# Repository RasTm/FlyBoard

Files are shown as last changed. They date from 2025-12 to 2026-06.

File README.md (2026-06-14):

Bu proje uçuş kontrol kartımız için gerekli yazılımım içermektedir. Proje tamamlandıkça bu bölüm kullanım klavuzu olarak değiştirilecektir.

Projeyi Atollic ile derleyebilmek için aşağıdaki işlemler yapılmalıdır.

1- Proje açılırken executable değil makefile olarak açılmalıdır.

2- C++ sürümü Properties (Alt+Enter) / C,C++ Build / Settings / Tool Settings / C++ Compiler / General başlığı altından C++ 11 olarak ayarlanmalıdır.

3- Properties (Alt+Enter) / C,C++ General / Paths and Symbols başlığına gidilip Includes, Library Paths, Source Location sekmelerine Libs klasörü eklenmelidir.

4- Properties (Alt+Enter) / C,C++ General / Paths and Symbols başlığına gidilip Includes ve Symbols sekmelerinden STD_Lib ile alakalı her şey kaldırılmalıdır. 

5- Libraries klasöründeki STD_periph klasörü kaldırılmalıdır. 

6- Libraries/Cmsis klasörü içerisine DSP_Lib ve Include klasörleri atılmalıdır eğer uyarı verirse orijinal dosyaların üzerine yazılmalıdır.

7- stm32f4xx_conf.h dosyasında eklenmiş tüm Stdlib kütüphaneleri kaldırılmalıdır.

8- Float değerleri LCD ekran üzerine yazdırmak için snprint fonksiyonu modifiye edilmelidir. Bunun için Properties (Alt+Enter) / C,C++ Build / Settings / Tool Settings / C++ Linker başlığı içerisinde Command alt başlığına "-u_printf_float" ifadesi yazılmalıdır.

9- Debug ekranında başlatmadan önce main'de durmasını sağlayan breakpoint kaldırılmalı yoksa C++ ile geliştirme yaparken program kırılabilir. Kaldırmak için Configure Debug / Startup Scripts gidilmeli. Buranın en altından 
"# Set a breakpoint at main(). tbreak main" Silinmeli.

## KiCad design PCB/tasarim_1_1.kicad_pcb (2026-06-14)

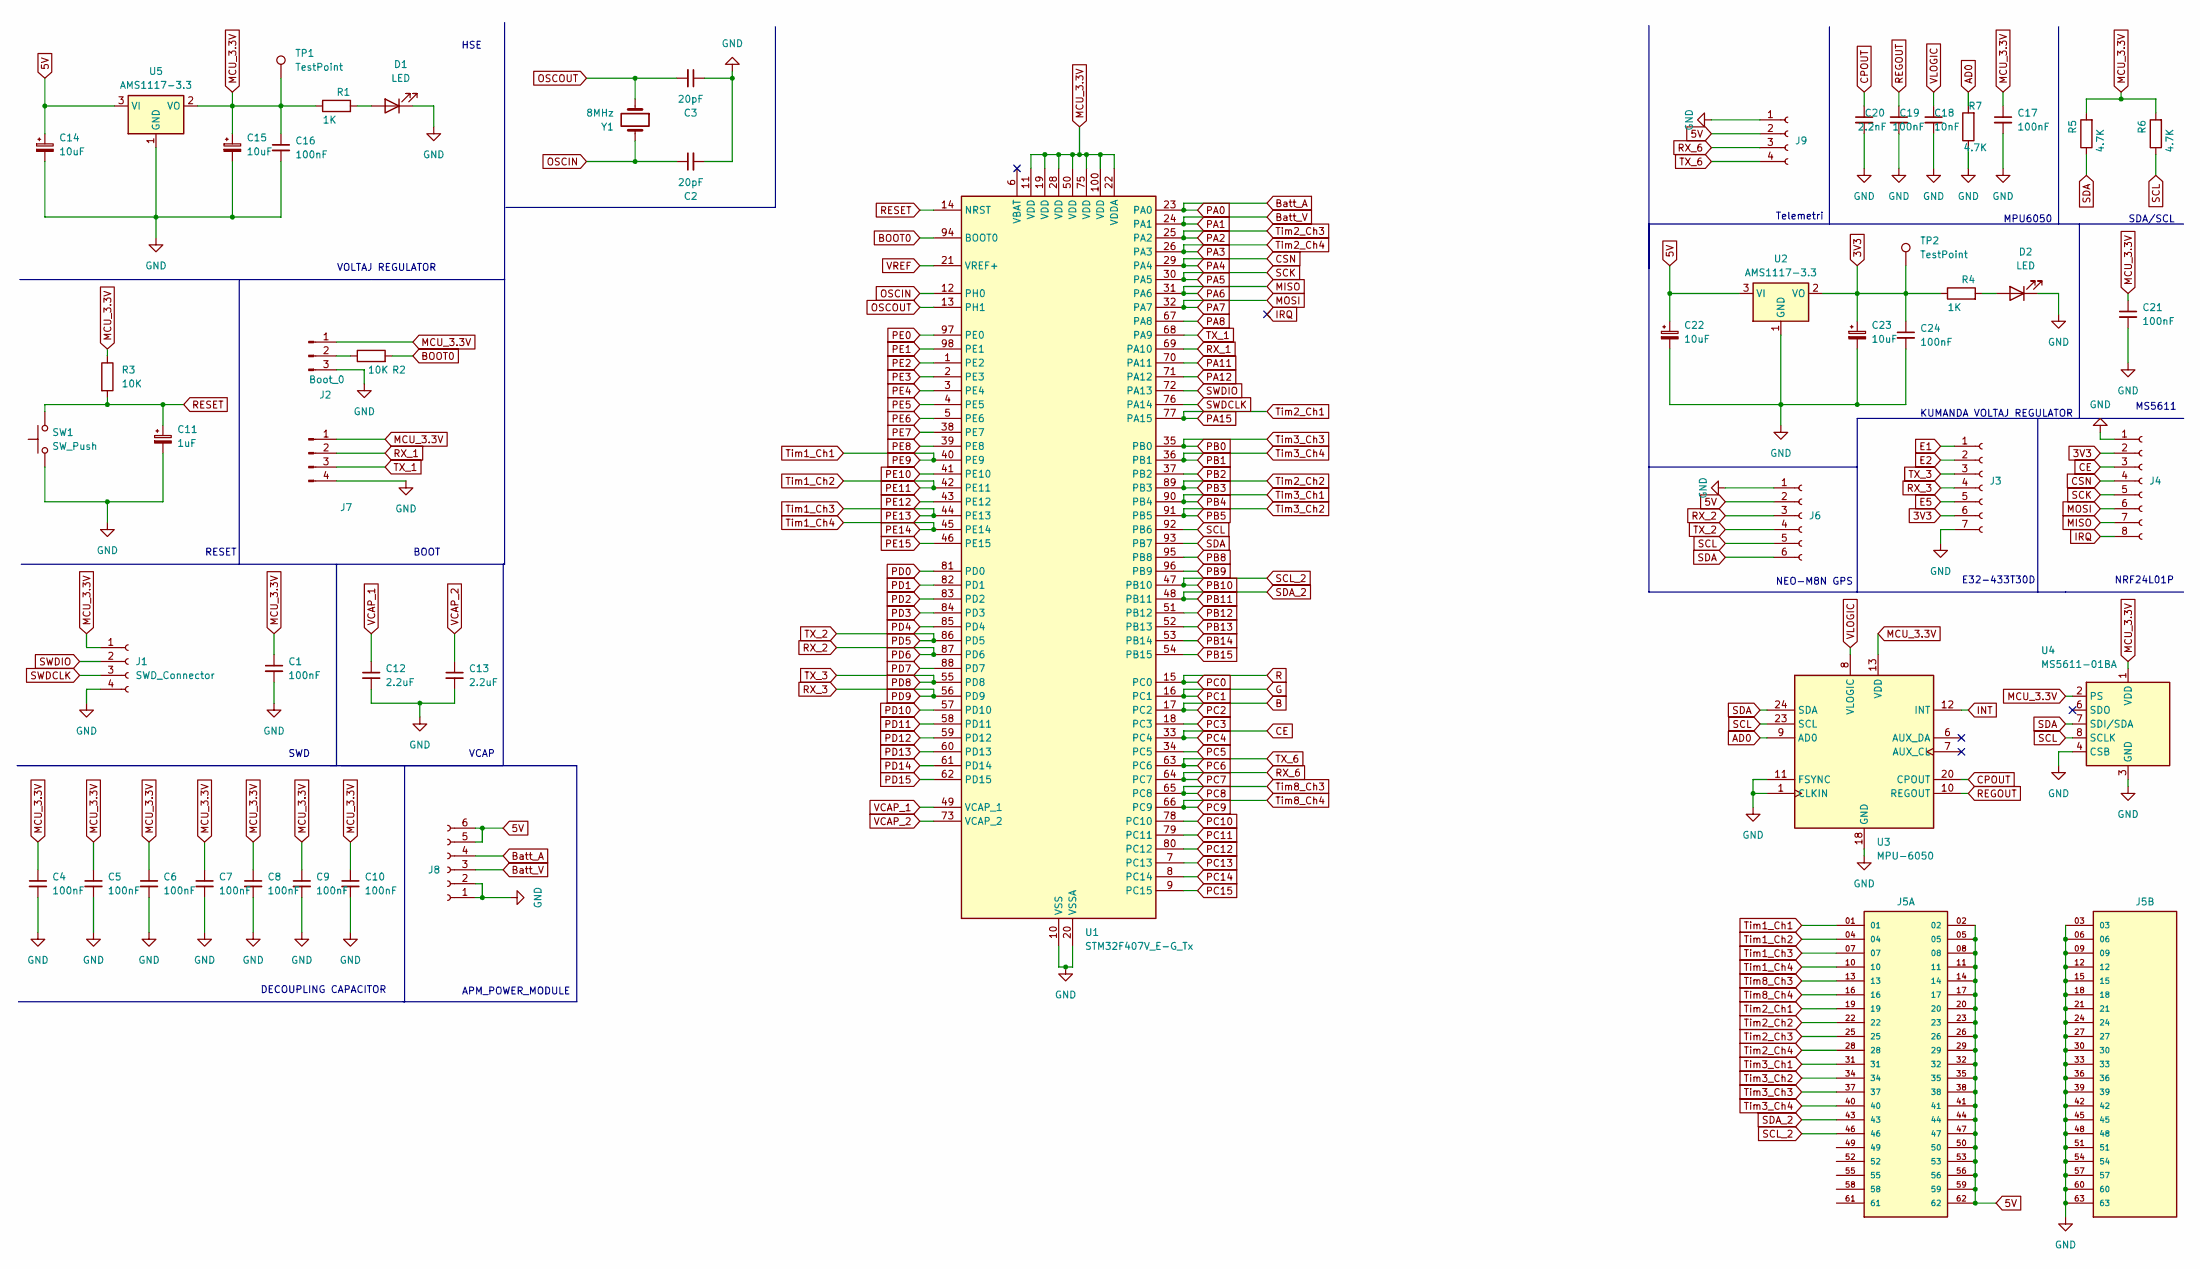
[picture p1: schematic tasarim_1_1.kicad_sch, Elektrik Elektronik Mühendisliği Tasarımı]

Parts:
C1, C4, C5, C6, C7, C8, C9, C10, C16, C17, C19, C21, C24: 100nF; C_0603_1608Metric
C2, C3: 20pF; C_0603_1608Metric
C11: 1uF; CP_EIA-1608-08_AVX-J
C12, C13: 2.2uF; CP_EIA-1608-08_AVX-J
C14, C15, C22, C23: 10uF; CP_EIA-1608-08_AVX-J
C18: 10nF; C_0603_1608Metric
C20: 2.2nF; C_0603_1608Metric
D1, D2: LED; LED_0805_2012Metric
J1: SWD_Connector; PinHeader_1x04_P2.54mm_Horizontal
J2: Boot_0; PinHeader_1x03_P2.54mm_Vertical
J3: LORA_Connector; JST_PH_B7B-PH-K_1x07_P2.00mm_Vertical
J4: NRF_Connector; JST_PH_B8B-PH-K_1x08_P2.00mm_Vertical
J5: ZW-21-08-L-T-200-157; SAMTEC_ZW-21-08-L-T-200-157; PARTREV R
J6: GPS_Connector; Hirose_DF13-06P-1.25DSA_1x06_P1.25mm_Vertical
J7: Bootloader_Port; PinHeader_1x04_P2.54mm_Vertical
J8: APM_Connector; Hirose_DF13-06P-1.25DSA_1x06_P1.25mm_Vertical
J9: Telemetri; JST_PH_B4B-PH-K_1x04_P2.00mm_Vertical
R1, R4: 1K; R_0603_1608Metric
R2, R3: 10K; R_0603_1608Metric
R5, R6, R7: 4.7K; R_0603_1608Metric
SW1: SW_Push; SW_PUSH_6mm_H5mm
TP1, TP2: TestPoint; TestPoint_Pad_D1.0mm
U1: STM32F407V_E-G_Tx; LQFP-100_14x14mm_P0.5mm
U2, U5: AMS1117-3.3; SOT-223-3_TabPin2
U3: MPU-6050; InvenSense_QFN-24_4x4mm_P0.5mm
U4: MS5611-01BA; LGA-8_3x5mm_P1.25mm
Y1: 8MHz; Crystal_HC49-4H_Vertical

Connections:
3V3: C23.1, C24.1, J3.6, J4.2, R4.1, TP2.1, U2.2 (VO)
5V: C14.1, C22.1, J5.02, J5.05, J5.08, J5.11, J5.14, J5.17, J5.20, J5.23, J5.26, J5.29, J5.32, J5.35, J5.38, J5.41, J5.44, J5.47, J5.50, J5.53, J5.56, J5.59, J5.62, J6.2, J8.5, J8.6, J9.2, U2.3 (VI), U5.3 (VI)
AD0: R7.2, U3.9 (AD0)
B: U1.17 (PC2)
BOOT0: R2.2, U1.94 (BOOT0)
Batt_A: J8.4, U1.23 (PA0)
Batt_V: J8.3, U1.24 (PA1)
CE: J4.3, U1.33 (PC4)
CPOUT: C20.1, U3.20 (CPOUT)
CSN: J4.4, U1.29 (PA4)
E1: J3.1
E2: J3.2
E5: J3.5
G: U1.16 (PC1)
GND: C1.2, C2.2, C3.1, C4.2, C5.2, C6.2, C7.2, C8.2, C9.2, C10.2, C11.2, C12.2, C13.2, C14.2, C15.2, C16.2, C17.2, C18.2, C19.2, C20.2, C21.2, C22.2, C23.2, C24.2, D1.1 (K), D2.1 (K), J1.4, J2.3, J3.7, J4.1, J5.03, J5.06, J5.09, J5.12, J5.15, J5.18, J5.21, J5.24, J5.27, J5.30, J5.33, J5.36, J5.39, J5.42, J5.45, J5.48, J5.51, J5.54, J5.57, J5.60, J5.63, J6.1, J7.4, J8.1, J8.2, J9.1, R7.1, SW1.1, U1.10 (VSS), U1.20 (VSSA), U1.27 (VSS), U1.74 (VSS), U1.99 (VSS), U2.1 (GND), U3.1 (CLKIN), U3.11 (FSYNC), U3.18 (GND), U4.3 (GND), U4.4 (CSB), U4.5 (CSB), U5.1 (GND)
INT: U3.12 (INT)
IRQ: J4.8
MCU_3.3V: C1.1, C4.1, C5.1, C6.1, C7.1, C8.1, C9.1, C10.1, C15.1, C16.1, C17.1, C21.1, J1.1, J2.1, J7.1, R1.1, R3.1, R5.2, R6.2, TP1.1, U1.11 (VDD), U1.19 (VDD), U1.22 (VDDA), U1.28 (VDD), U1.50 (VDD), U1.75 (VDD), U1.100 (VDD), U3.13 (VDD), U4.1 (VDD), U4.2 (PS), U5.2 (VO)
MISO: J4.7, U1.31 (PA6)
MOSI: J4.6, U1.32 (PA7)
unnamed: D1.2 (A), R1.2
unnamed: D2.2 (A), R4.2
unnamed: J2.2, R2.1
OSCIN: C2.1, U1.12 (PH0), Y1.2
OSCOUT: C3.2, U1.13 (PH1), Y1.1
PA2: J5.25, U1.25 (PA2)
PA3: J5.28, U1.26 (PA3)
PA5: J4.5, U1.30 (PA5)
PA8: U1.67 (PA8)
PA11: U1.70 (PA11)
PA12: U1.71 (PA12)
PA15: J5.19, U1.77 (PA15)
PB0: J5.37, U1.35 (PB0)
PB1: J5.40, U1.36 (PB1)
PB2: U1.37 (PB2)
PB3: J5.22, U1.89 (PB3)
PB4: J5.31, U1.90 (PB4)
PB5: J5.34, U1.91 (PB5)
PB8: U1.95 (PB8)
PB9: U1.96 (PB9)
PB10: J5.46, U1.47 (PB10)
PB11: J5.43, U1.48 (PB11)
PB12: U1.51 (PB12)
PB13: U1.52 (PB13)
PB14: U1.53 (PB14)
PB15: U1.54 (PB15)
PC0: U1.15 (PC0)
PC3: U1.18 (PC3)
PC5: U1.34 (PC5)
PC6: J9.4, U1.63 (PC6)
PC7: J9.3, U1.64 (PC7)
PC8: J5.13, U1.65 (PC8)
PC9: J5.16, U1.66 (PC9)
PC10: U1.78 (PC10)
PC11: U1.79 (PC11)
PC12: U1.80 (PC12)
PC13: U1.7 (PC13)
PC14: U1.8 (PC14)
PC15: U1.9 (PC15)
PD0: U1.81 (PD0)
PD1: U1.82 (PD1)
PD2: U1.83 (PD2)
PD3: U1.84 (PD3)
PD4: U1.85 (PD4)
PD5: J6.4, U1.86 (PD5)
PD6: J6.3, U1.87 (PD6)
PD7: U1.88 (PD7)
PD8: J3.3, U1.55 (PD8)
PD9: J3.4, U1.56 (PD9)
PD10: U1.57 (PD10)
PD11: U1.58 (PD11)
PD12: U1.59 (PD12)
PD13: U1.60 (PD13)
PD14: U1.61 (PD14)
PD15: U1.62 (PD15)
PE0: U1.97 (PE0)
PE1: U1.98 (PE1)
PE2: U1.1 (PE2)
PE3: U1.2 (PE3)
PE4: U1.3 (PE4)
PE5: U1.4 (PE5)
PE6: U1.5 (PE6)
PE7: U1.38 (PE7)
PE8: U1.39 (PE8)
PE9: J5.01, U1.40 (PE9)
PE10: U1.41 (PE10)
PE11: J5.04, U1.42 (PE11)
PE12: U1.43 (PE12)
PE13: J5.07, U1.44 (PE13)
PE14: J5.10, U1.45 (PE14)
PE15: U1.46 (PE15)
REGOUT: C19.1, U3.10 (REGOUT)
RESET: C11.1, R3.2, SW1.2, U1.14 (NRST)
RX_1: J7.2, U1.69 (PA10)
SCL: J6.5, R6.1, U1.92 (PB6), U3.23 (SCL), U4.8 (SCLK)
SDA: J6.6, R5.1, U1.93 (PB7), U3.24 (SDA), U4.7 (SDI/SDA)
SWDCLK: J1.3, U1.76 (PA14)
SWDIO: J1.2, U1.72 (PA13)
TX_1: J7.3, U1.68 (PA9)
VCAP_1: C12.1, U1.49 (VCAP_1)
VCAP_2: C13.1, U1.73 (VCAP_2)
VLOGIC: C18.1, U3.8 (VLOGIC)
VREF: U1.21 (VREF+)

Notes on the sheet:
VCAP
RESET
DECOUPLING CAPACITOR
HSE
SWD
MPU6050
BOOT
NEO-M8N GPS
APM_POWER_MODULE
NRF24L01P
Telemetri
E32-433T30D
MS5611
KUMANDA VOLTAJ REGULATOR
VOLTAJ REGULATOR
SDA/SCL

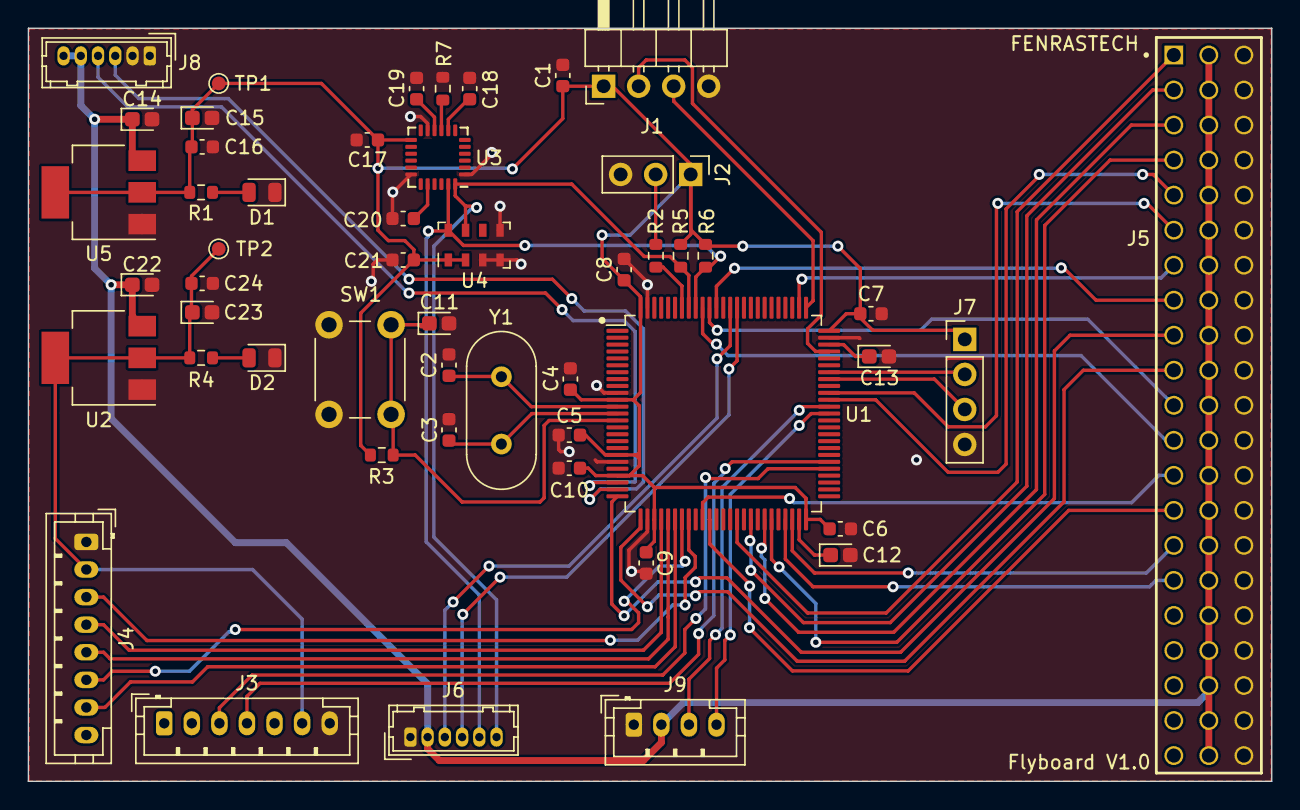
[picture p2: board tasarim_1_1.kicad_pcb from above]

Board: 2 copper layers, 90.2 x 54.6 mm, 51 parts (0 on the bottom side), 52 nets.

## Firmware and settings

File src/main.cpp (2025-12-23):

/*********************************************************
 *  In The End, What Separates A Man From A Slave?       *
 *  Money? Power? No.                                    *
 *  A Man Chooses A Slave Obeys                          *
 *                                          ~Andrew Ryan~*
 *********************************************************/

#include "main.h"

void Program_timer(){
	RCC-> APB1ENR |= 0x00000100;             //Timer14 Clock Enable
	TIM14-> DIER  |= 0x0001;                 //Update Interrupt Enable
	TIM14-> PSC    = 83;                     //Tout = ((PSC+1)*(ARR+1))/Tim_clk) -> Tim_clk = 84Mhz
	TIM14-> ARR    = 999;                    //Tout must be 1ms
	TIM14-> CR1   |= 0x0085;                 //ARPE Enable ,URS and CEN Enable
}
void PPM_read_timer(){
	RCC-> APB1ENR  |= 0x00000080;             //Timer13 Clock Enable
	TIM13-> PSC     = 83;                     //Tout = ((PSC+1)*(ARR+1))/Tim_clk) -> Tim_clk = 84Mhz
	TIM13-> ARR     = 39999;                  //Tout = 40ms For Ppm Failsafe (2 frame)
	TIM13-> DIER   |= 0x0001;                 //Timer13 Updade Interrupt Enable
	TIM13-> CR1    |= 0x0001;                 //Timer13 Counter Start
	gpio_config(GPIOE,11,INPUT,PUSH,LOW,UP,SyS);   //GPIOE 11 Configure
}
void DMA2_init(){
	DMA2_Stream0-> CR |=
			DMA_SxCR_MSIZE_0 |                //16 bit Memory Adress Size
			DMA_SxCR_PSIZE_0 |                //16 bit Perpipheral Adress Size (ADC1-> DR)
			DMA_SxCR_MINC    |                //Memory Increment Mode
			DMA_SxCR_CIRC    |                //Circular Mode
			DMA_SxCR_TCIE;                    //Transfer Complete Interrupt

	DMA2_Stream0-> NDTR = 2;
	DMA2_Stream0-> PAR  = (uint32_t) &ADC1->DR;
	DMA2_Stream0-> M0AR = (uint32_t) &adc_avg[0];

	DMA2_Stream0->CR |= 0x00000001;

}
void interrupt_init(){
	Set_Interrupt(TIM8_TRG_COM_TIM14_IRQn,1);
	Set_Interrupt(TIM8_UP_TIM13_IRQn,2);
	Set_Interrupt(DMA2_Stream0_IRQn,0);
	Set_Interrupt(EXTI15_10_IRQn,0);

	Set_Ext_Interrupt(11,GPIO_E,RISING);
}

int main(void){
	Clock_init();
	Program_timer();
	PPM_read_timer();
	DMA2_init();
	I2C_Base::I2C_recover(I2C1);

	ADC_Base batt_V(ADC_1, 1, 0, 7);                                         //GPIOA 1, first, sample = 7
	ADC_Base batt_A(ADC_1, 0, 1, 7);                                         //GPIOA 0, second, sample = 7
	ADC_Base::ADC_dma_enable(ADC1);
	ADC_Base::ADC_scan_enable(ADC1);
	ADC_Base::ADC_continuous_enable(ADC1);

	USART_Base Serial(USART_1, 115200);
	USART_Base Telemetry(USART_6, 57600);

	Serial.USART_Transmit(motivation);
	delay(1000);
	Serial.USART_Transmit(clear_disp);
	Serial.USART_Transmit(project_header);

	Serial.USART_Transmit("MPU6050 Starting");
	MPU6050 mpu(I2C1, STANDARD, MPU6050_FS_SEL1, MPU6050_FS_SEL1);
 	mpu.config();
	Serial.USART_Transmit("\n\rCalibrating...");
	mpu.calc_IMU_error();
	mpu.gyro_constant = (float)(1.0/250.0/mpu.gyro_fs_val);                  //250 Hz Refresh rate
	Serial.USART_Transmit("\033[2K\rCalibration Done Gyro Constant = ");
	Serial.USART_Transmit_float(mpu.gyro_constant,8);
	delay(500);
	Serial.USART_Transmit(clear_disp);

	Serial.USART_Transmit("MS5611 Starting\n");
	MS5611 ms5611(I2C1);
	ms5611.get_coefficent();
	Serial.USART_Transmit(clear_line);
	Serial.USART_Transmit("MS5611 Done\n");
	delay(1000);
	Serial.USART_Transmit(clear_line);

//	Serial.USART_Transmit("HMC5883L Starting");
//	HMC5883 hmc(I2C1);
//	hmc.config();
//	delay(50);
//	Serial.USART_Transmit(clear_line);

	Serial.USART_Transmit("Roll\tPitch\tAltitude\tPreassure\tTemp\tVolt\tAmper\n\r");

	interrupt_init();
	ADC_Base::ADC_start(ADC1);

	while (1){
		if(program_buffer[read_index] != 0){read_index++;}
		if(read_index == PROG_BUFF_SIZE){ read_index = 0;}

		if(program_buffer[read_index] == MPU6050_FLAG){
			mpu_Hz_counter++;
			mpu.get_gyro(raw_gyro);
			mpu.get_accel(raw_accel);

			raw_accel[0] -= mpu.imu_calibration_error[0];
			raw_accel[1] -= mpu.imu_calibration_error[1];
			raw_accel[2] -= mpu.imu_calibration_error[2];

			raw_gyro[0]  -= mpu.imu_calibration_error[3];
			raw_gyro[1]  -= mpu.imu_calibration_error[4];
			raw_gyro[2]  -= mpu.imu_calibration_error[5];

			gyro_pitch += raw_gyro[0] * mpu.gyro_constant;
			gyro_roll  += raw_gyro[1] * mpu.gyro_constant;

			old_gyro_pitch = gyro_pitch;
			old_gyro_roll  = gyro_roll;

			gyro_pitch += old_gyro_roll  * arm_sin_f32((raw_gyro[2] * mpu.gyro_constant)*RAD_TO_DEG);
			gyro_roll  -= old_gyro_pitch * arm_sin_f32((raw_gyro[2] * mpu.gyro_constant)*RAD_TO_DEG);

			acc_total_vec = sqrt((raw_accel[0]*raw_accel[0])+(raw_accel[1]*raw_accel[1])+(raw_accel[2]*raw_accel[2]));
			acc_pitch = asin((float)raw_accel[1]/(float)acc_total_vec)* RAD_TO_DEG;
			acc_roll  = asin((float)raw_accel[0]/(float)acc_total_vec)*-RAD_TO_DEG;

			if(mpu.set_gyro_angles){
				gyro_pitch = (gyro_pitch * 0.8) + (acc_pitch * 0.2);
				gyro_roll  = (gyro_roll  * 0.8) + (acc_roll  * 0.2);
			}
			else{
				mpu.set_gyro_angles = true;
				gyro_pitch = acc_pitch;
				gyro_roll  = acc_roll;
			}
			final_pitch = gyro_pitch;
			final_roll  = gyro_roll ;
		}

		if(program_buffer[read_index] == MS5611_FLAG){
			ms_Hz_counter++;
			ms5611.calculate_absolute_val(data,altitude);
		}

//	    if(program_buffer[read_index] == HMC5883_FLAG){
//			hmc_Hz_counter++;
//			hmc.mag_conv(heading_degree);
//		}

		if(adc_read_able){
			if(local_adc[0] > 520){
				adc[0] = ((3.3/4096.0)*(float)(local_adc[0]+50))*10;
			}
			adc[1] = ((3.3/4096.0)*(float)(local_adc[1]))/0.028;
			adc_read_able = false;
		}

		if(read_index % 2 ==0){
			Serial.Transmit(final_roll);
			Serial.USART_Transmit("\t");
			Serial.Transmit(final_pitch);
			Serial.USART_Transmit("\t");
			Serial.Transmit(altitude);
			Serial.USART_Transmit("\t");
			Serial.Transmit(data[0]);
			Serial.USART_Transmit("\t");
			Serial.Transmit(data[1]);
			Serial.USART_Transmit("\t");
//			Serial.Transmit(heading_degree);
//			Serial.USART_Transmit("\t");
//			Serial.Transmit(hmc_Hz);
//			Serial.USART_Transmit("\t");
			Serial.Transmit(adc[0]);
			Serial.USART_Transmit("\t");
			Serial.Transmit(adc[1]);
//			Serial.USART_Transmit("\t");
//			Serial.Transmit(remote_ppm.channelX[2]);
//			Serial.USART_Transmit("\t");
//			Serial.Transmit(remote_ppm.channelX[3]);
//			Serial.USART_Transmit("\t");
//			Serial.Transmit(remote_ppm.channelX[4]);
//			Serial.USART_Transmit("\t");
//			Serial.Transmit(remote_ppm.channelX[5]);
//			Serial.USART_Transmit("\t");
//			Serial.Transmit(remote_ppm.channelX[6]);
//			Serial.USART_Transmit("\t");
//			Serial.Transmit(remote_ppm.channelX[7]);
			Serial.USART_Transmit("\n\r");
/*
			sayac2++;
			if(sayac2 == 5){
				sayac2 = 0;
				Serial.USART_Transmit("\033[5A\r\033[0J"); //5 row up, go row begining erase everything below
			}*/
		}
	}
}

extern "C" { void TIM8_TRG_COM_TIM14_IRQHandler(void){
		if(TIM14-> SR & 0x0001){
		TIM14-> SR = 0;
		mpu_tick++;
		ms_tick++;
		hmc_tick++;
		program_Hz_counter++;

		if(write_index == PROG_BUFF_SIZE-1 && read_index < PROG_BUFF_SIZE){
			write_index = 0;
			buffer_write_able = false;
		}
		else{buffer_write_able = true;}

		if(buffer_write_able == true){
			if(mpu_tick > 2){
				mpu_tick = 0;
				if(write_index < 12){
					program_buffer[write_index] = MPU6050_FLAG;
					write_index++;
				}
			}
			if(ms_tick > 11){
				ms_tick = 0;
				if(write_index < 12){
					program_buffer[write_index] = MS5611_FLAG;
					write_index++;
				}
			}
			if(hmc_tick > 10){
				hmc_tick = 0;
				if(write_index < 12){
					program_buffer[write_index] = HMC5883_FLAG;
					write_index++;
				}
			}
		}

		if(program_Hz_counter == 1000){
			mpu_Hz = mpu_Hz_counter;
			ms_Hz  = ms_Hz_counter / 4;
			hmc_Hz = hmc_Hz_counter;
			program_Hz_counter = 0;
			mpu_Hz_counter = 0;
			ms_Hz_counter  = 0;
			hmc_Hz_counter = 0;
		}
		Clr_Interrupt_PD(TIM8_TRG_COM_TIM14_IRQn);
	}
}}

extern "C" { void EXTI15_10_IRQHandler(void) {
	remote_ppm.current_time = TIM13-> CNT;

	if(!remote_ppm.first_valid_edge){						//First valid edge check if true go out from function
		remote_ppm.last_time = remote_ppm.current_time;
		remote_ppm.first_valid_edge = true;
		Clr_Ext_Interrupt_PD(11);
		Clr_Interrupt_PD(EXTI15_10_IRQn);
		return;
	}

    remote_ppm.current_time = TIM13->CNT;
	remote_ppm.delta = (uint16_t) remote_ppm.current_time - remote_ppm.last_time;
	remote_ppm.last_time = remote_ppm.current_time;

	if(!remote_ppm.dead_space_seen) {						//Sync space check if true return pointer to begining
		if(remote_ppm.delta > 4000){
			remote_ppm.dead_space_seen = true;
			remote_ppm.i = 0;
		}
	}
	else{
		if(remote_ppm.i < 8){
			remote_ppm.channelX[remote_ppm.i] = remote_ppm.delta - 2;  // - 2 is for calibration
			remote_ppm.i += 1;
		}
		if(remote_ppm.i == 8){
			remote_ppm.dead_space_seen = false;
			remote_ppm.i = 0;
			remote_ppm.remote_frame_lost_counter = 0;
		}
	}

	Clr_Ext_Interrupt_PD(11);
	Clr_Interrupt_PD(EXTI15_10_IRQn);
}}

extern "C" { void TIM8_UP_TIM13_IRQHandler(void){
	if(TIM13-> SR & 0x0001){
		TIM13-> SR = 0;
		remote_ppm.remote_frame_lost_counter++;
		if(remote_ppm.remote_frame_lost_counter == 2){
			remote_ppm.remote_frame_lost_counter = 2;
			remote_ppm.first_valid_edge = false;
			remote_ppm.dead_space_seen  = false;
			remote_ppm.channelX[0] = 0;
			remote_ppm.channelX[1] = 0;
			remote_ppm.channelX[2] = 0;
			remote_ppm.channelX[3] = 0;
			remote_ppm.channelX[4] = 0;
			remote_ppm.channelX[5] = 0;
			remote_ppm.channelX[6] = 0;
			remote_ppm.channelX[7] = 0;
		}
		Clr_Interrupt_PD(TIM8_UP_TIM13_IRQn);
	}
}}

extern "C" { void DMA2_Stream0_IRQHandler(void){
	if(DMA2-> LISR & 0x00000020){
		DMA2-> LIFCR = 0x00000020;
		local_adc[0] = adc_avg[0];
		local_adc[1] = adc_avg[1];
		adc_read_able = true;
		Clr_Interrupt_PD(DMA2_Stream0_IRQn);
	}
}}

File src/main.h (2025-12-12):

#ifndef MAIN_H_
#define MAIN_H_

/*
 * All Libraries We Use For FC
 */
#include "stm32f4xx.h"
#include "arm_math.h"
#include "stdlib.h"

#include "../Libs/RCC.hpp"
#include "../Libs/ADC.hpp"
#include "../Libs/DMA.hpp"
#include "../Libs/GPIO.hpp"
#include "../Libs/Nvic.hpp"
#include "../Libs/USART.hpp"
#include "../Libs/Remote.hpp"
#include "../Libs/Ms5611.hpp"
#include "../Libs/Mpu6050.hpp"
#include "../Libs/Hmc5883L.hpp"

/*
 * Some Pre Defined Things
 */
#define PROG_BUFF_SIZE 12
#define MPU6050_FLAG 1
#define MS5611_FLAG  2
#define HMC5883_FLAG 3

#define MPU6050_TICK 2
#define MS5611_TICK  11
#define HMC5883_TICK 10

/*
 * Constant Variables
 */
const uint8_t project_header[]  = "Flyboard Pertinax v1.0\n\r";
const uint8_t motivation[]	=
		"\n\r*********************************************************"
		"\n\r*  In The End, What Separates A Man From A Slave?       *"
		"\n\r*  Money? Power? No.                                    *"
		"\n\r*  A Man Chooses A Slave Obeys                          *"
		"\n\r*                                          <Andrew Ryan>*"
		"\n\r*********************************************************";
const uint8_t clear_disp[] = "\033[2J\033[H";
const uint8_t clear_line[] = "\033[2K\r";

/*
 * Variables
 */
uint8_t program_buffer[PROG_BUFF_SIZE] = {0}, buffer_write_able = true;
volatile uint8_t write_index = 0, read_index = 0;

uint8_t  sayac2=0;
uint32_t mpu_Hz_counter=0, mpu_Hz=0, mpu_tick=0,
		 ms_Hz_counter=0, ms_Hz=0, ms_tick=0,
		 hmc_Hz_counter=0, hmc_Hz=0, hmc_tick=0,
		 program_Hz_counter=0;

//MPU6050 Variables
int16_t raw_gyro[3] = {0}, raw_accel[3] = {0};
uint32_t acc_total_vec=0;
float old_gyro_roll=0.0, old_gyro_pitch=0.0, gyro_pitch=0.0, gyro_roll=0.0, acc_pitch=0.0, acc_roll=0.0;
float final_pitch=0.0, final_roll=0.0;

//MS5611 Variables
double data[2] = {0.0}, altitude = 0.0;

//HMC5883L Variables
float heading_degree = 0.0;

//PPM
PPM remote_ppm;

//ADC
uint32_t adc_avg[2] = {0};
uint32_t local_adc[2] = {0};
float64_t adc[2];
bool adc_read_able = false;

#endif

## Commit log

2025-03-22 Gyro Formula Fix
2025-03-22 Minor Fix, Hz calculation
    MPU6050 calculation loop frequency measurement
    [main.cpp]
2025-03-25 comment line spacing fix
    [main.cpp]
2025-03-28 Flyboard V1.0 PCB
    KiCAD PCB files
    [tasarim_1_1.kicad_pcb, tasarim_1_1.kicad_sch]
2025-04-13 Uart 6 connect to ST-LINK V2
    so we need to change baud rate to 9600
2025-04-14 program management intrrupt fix, baud rate fix for low Hz
    [main.cpp]
2025-04-15 Fake Sensor I2C Address Update
2025-04-15 systick timer minor fix
2025-05-18 PCB test main code
2025-05-24 add new functions, optimize current functions and names
2025-05-24 new i2c recover function added
    i2c recover function does i2c pin high and reset so it prevents to
    locking i2c situations
    [main.cpp]
2025-05-26 solve interrupt priority problem
2025-05-31 i2c recover added inside the library
2025-05-31 new ppm interrupt
2025-06-01 solve sensor malfunction with software
2025-06-01 ppm failsafe uses tim13 update interrupt
    [main.cpp]
2025-06-02 new adc configuration and new static functions added
2025-06-05 added new disable funcitons in ADC lib
2025-06-05 new adc read tryout
2025-06-09 new adc dma function added
2025-06-09 dma 1 and 2 clocks enable
2025-06-09 new adc dma readings added
2025-06-20 uart rx lines pull up
2025-06-20 new adc, dma and more
2025-12-12 main.h added
    main.h added, i2c periph fast mode update, dma periph driver starting
    develop
2025-12-22 small changes
    gpio reset function improved
    i2c improved
    i2c used sensor functions improved
    [main.cpp]
2026-06-14 new kicad version update
    [tasarim_1_1.kicad_pcb, tasarim_1_1.kicad_sch]
2026-10-18 kicad version update and various thigns
    0
